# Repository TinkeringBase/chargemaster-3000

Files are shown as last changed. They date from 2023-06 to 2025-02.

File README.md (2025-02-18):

[한국어](https://github.com/TinkeringBase/chargemaster-3000/blob/main/readme-ko.md)
# TinkeringBase Chargemaster-3000
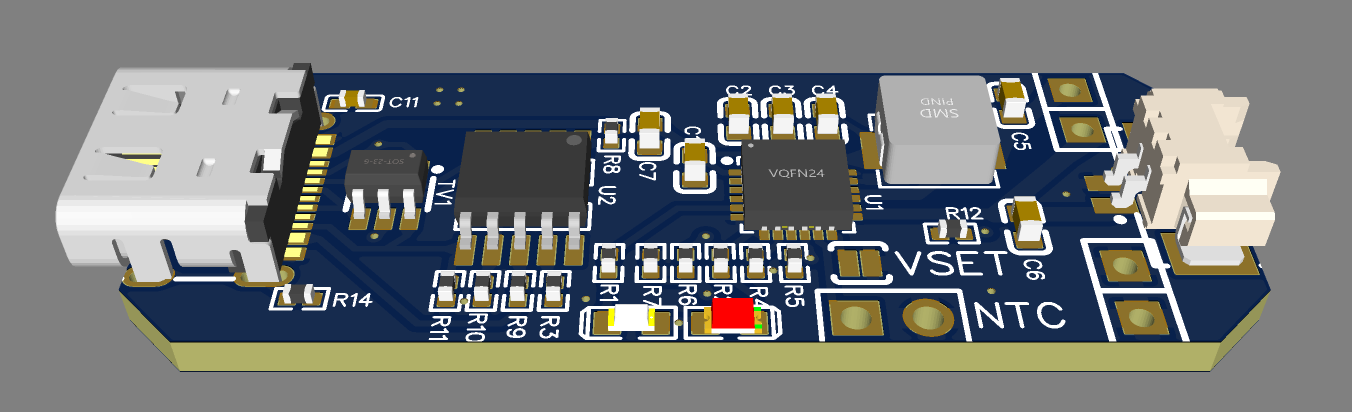
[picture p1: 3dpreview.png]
preview
\
Lithium ion/polymer battery charging module based on BQ25606. It can charge batteries at up to 3000mA speed. Its input section is protected with TVS. So it is kind of safe from ESD. Also, it act as USB-PD device to draw 9V. It provides overcharge protection, power path control, selectable max charging currnet. It can draw current from battery even while charging so you don't need to worry about low current situation.
## setting battery voltage
By default, battery voltage is set to 4.2V. You can set it to 4.35V by soldering VSET jumper.
## selecting max charging current
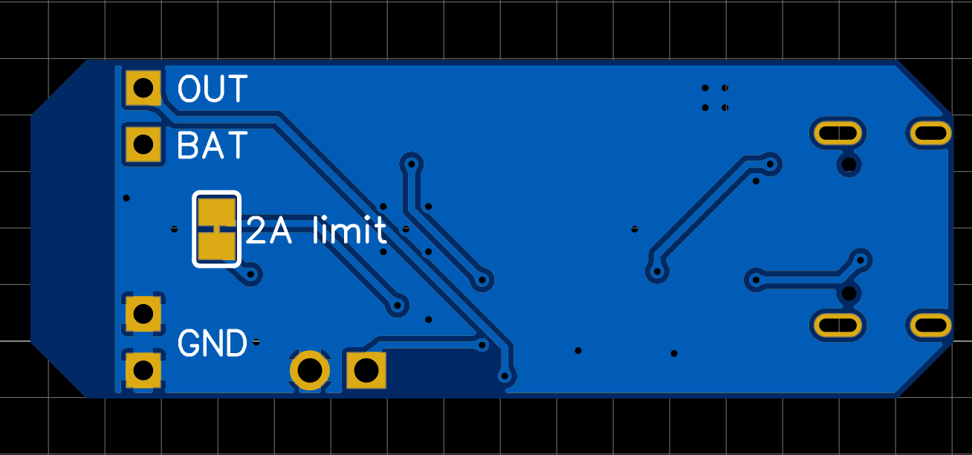
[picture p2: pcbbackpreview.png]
backpreview
\
Maximum charging current is set to 3A by default. You can reduce it to 2A by cutting the jumper on the back of the module. To set the current to 3A again, solder the jumper.
## warning about charging current
Do not charge the battery exeeding your battery's spec. The battery will be overheated and damaged, and possibly catch on fire. if your battery allows 0.5C charge rate and has capacity of 2000mAh, then maximum charging current is 1000mA. (2000*0.5)
## connector
it accepts MOLEX 51021 RB type connector. always check the polarity before connecting.\
adsf
### protection
unlike generic TP4056 module, this module does not provide overcurrent protection and overdischarge protection. you need to use protected battery pack or add external protection board.

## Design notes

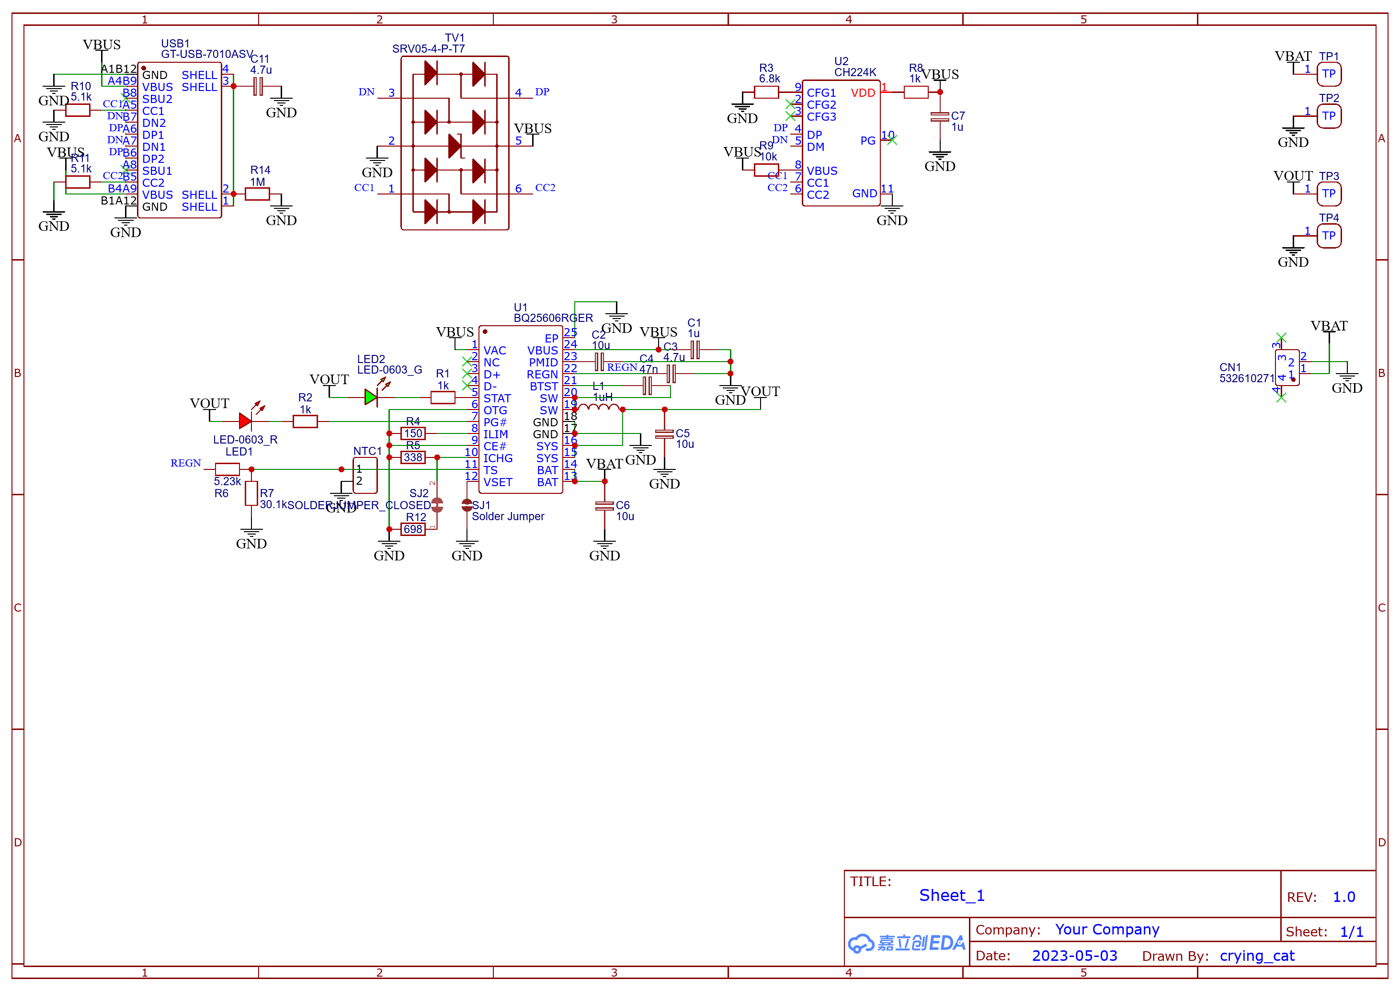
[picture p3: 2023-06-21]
Schematic.png

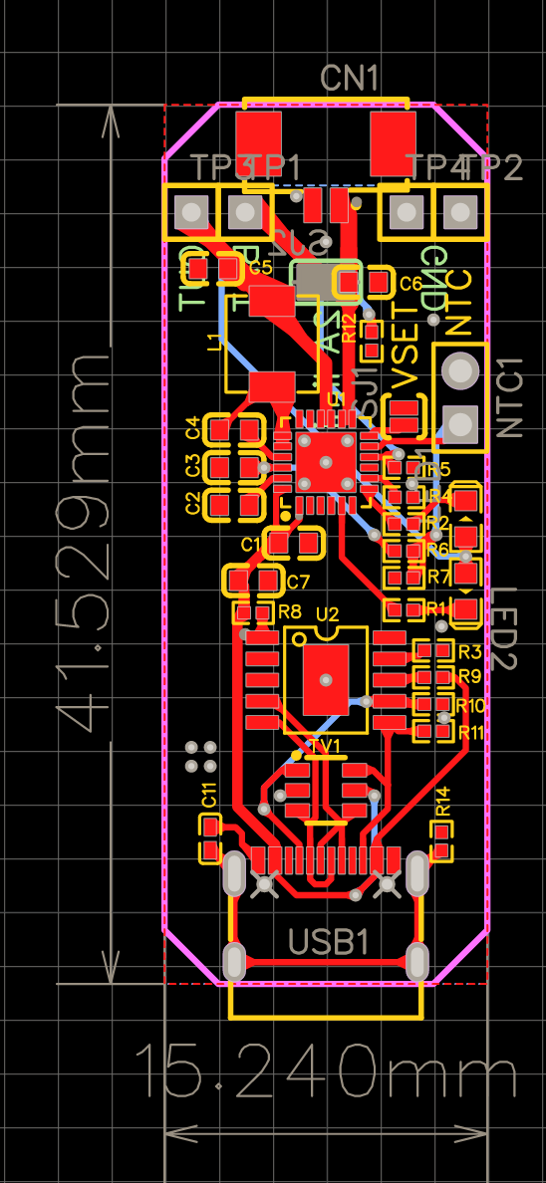
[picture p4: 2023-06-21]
pcbpreview.png

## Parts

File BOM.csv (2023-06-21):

ID | Name | Designator | Footprint | Quantity | Manufacturer Part | Manufacturer | Supplier | Supplier Part | Price
1 | SOLDERJUMPER_CLOSED | SJ2 | SOLDERJUMPER_CLOSEDWIRE | 1
2 | 338 | R5 | R0402 | 1
3 | 698 | R12 | R0402 | 1
4 | 532610271 | CN1 | CONN-SMD_532610271 | 1 | 532610271 | MOLEX | LCSC | C189700 | 0.119
5 | 1u | C1,C7 | C0603 | 2
6 | 10u | C2,C5,C6 | C0603 | 3
7 | 4.7u | C3 | C0603 | 1
8 | 47n | C4 | C0603 | 1
9 | 4.7u | C11 | C0402 | 1
10 | 1uH | L1 | IND-SMD_L4.4-W4.2 | 1 | MWSA0402S-1R0MT | Sunlord(顺络) | LCSC | C408332 | 0.139
11 | LED-0603_R | LED1 | LED0603_RED | 1 | 19-217/R6C-AL1M2VY/3T | EVERLIGHT(台湾亿光) | LCSC | C72044 | 0.017
12 | LED-0603_G | LED2 | LED0603_GREEN | 1 | 19-217/GHC-YR1S2/3T | EVERLIGHT(台湾亿光) | LCSC | C72043 | 0.027
13 | 1k | R1,R2,R8 | R0402 | 3
14 | 150 | R4 | R0402 | 1
15 | 5.23k | R6 | R0402 | 1
16 | 30.1k | R7 | R0402 | 1
17 | 6.8k | R3 | R0402 | 1
18 | 5.1k | R10,R11 | R0402 | 2
19 | 1M | R14 | R0402 | 1
20 | Solder Jumper | SJ1 | SOLDERJUMPER | 1
21 | SRV05-4-P-T7 | TV1 | SOT-23-6_L2.9-W1.6-P0.95-LS2.8-BR | 1 | SRV05-4-P-T7 | PROTEK | LCSC | C85364 | 0.176
22 | BQ25606RGER | U1 | VQFN-24_L4.0-W4.0-P0.50-TL-EP2.8 | 1 | BQ25606RGER | TI(德州仪器) | LCSC | C374063 | 0.931
23 | CH224K | U2 | ESSOP-10_L4.9-W3.9-P1.0-LS6.0-TL-EP | 1 | CH224K | WCH(南京沁恒) | LCSC | C970725 | 0.512
24 | GT-USB-7010ASV | USB1 | USB-C-SMD_G-SWITCH_GT-USB-7010ASV | 1 | GT-USB-7010ASV | G-Switch(品赞) | LCSC | C2988369 | 0.079
25 | 10k | R9 | R0402 | 1

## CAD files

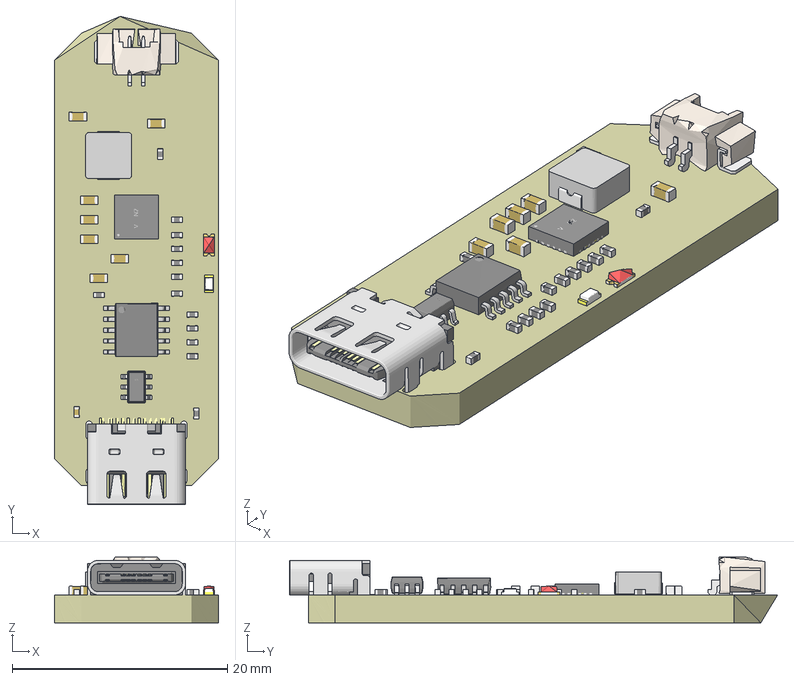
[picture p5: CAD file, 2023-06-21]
3D.3mf
15.2 x 45.4 x 6.11 mm
